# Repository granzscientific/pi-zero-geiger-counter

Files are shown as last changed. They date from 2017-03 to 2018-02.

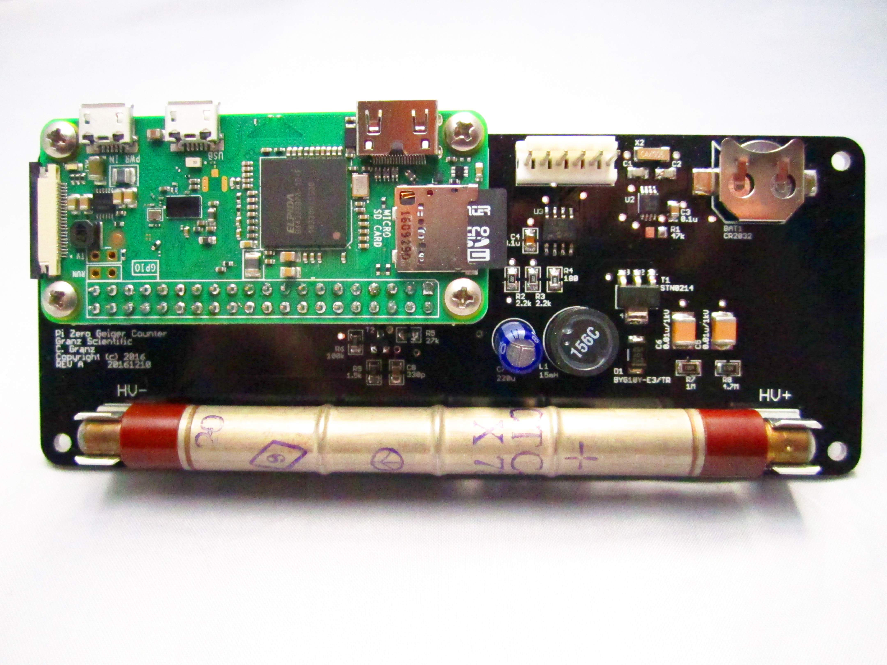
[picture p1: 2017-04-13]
images/REV A/IMG_2126.JPG

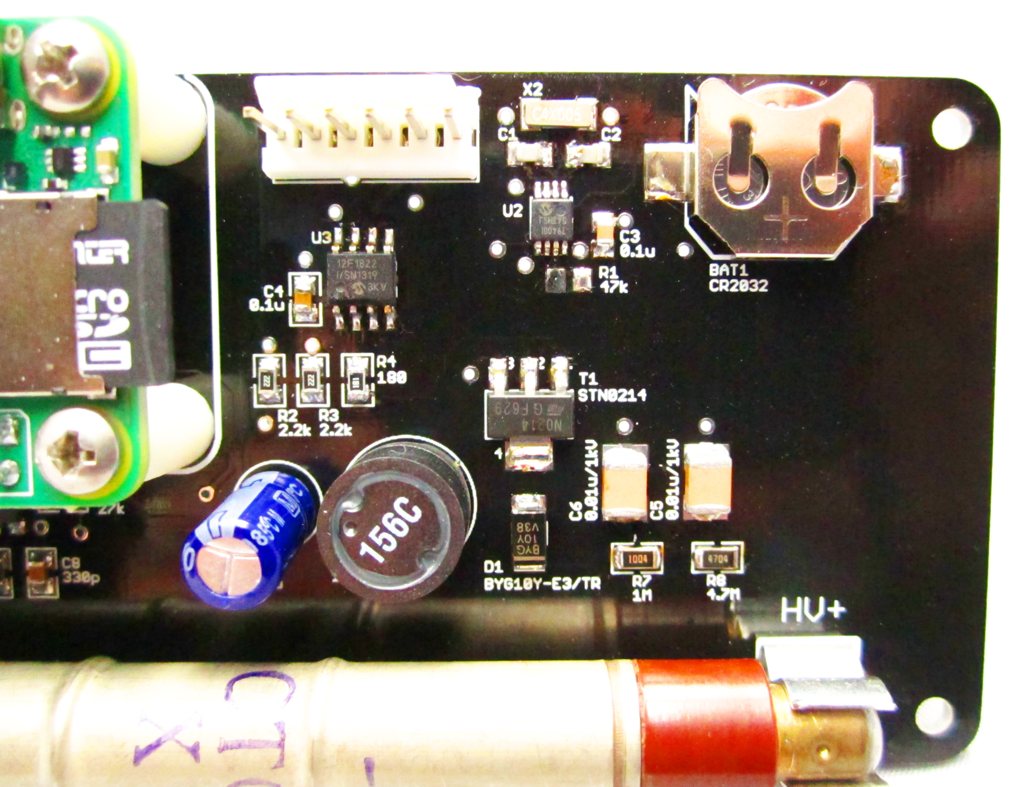
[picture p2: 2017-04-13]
images/REV A/IMG_2129.JPG

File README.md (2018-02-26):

# pyGI/webGI - A Web interface for the Granz Scientific Raspberry Pi Zero Geiger Counter

Python/HTML5/CSS/JS/Websocket software suite for collecting, distributing,
monitoring, mapping and analyzing ionizing radiation counts detected by the PiGI-Module.

This software stack is based on the Raspberry Pi Geiger Counter project described here:

http://projects-raspberry.com/pigi-raspberry-pi-geiger-muller-interface/

and here:

https://apollo.open-resource.org/lab:pigi

## Sneak-Preview: Development screenshots in action

### Main instrument panel

### History instrument panel

### Ion trace visualizer


## Installation

### Dependencies

We've tried to keep external dependencies to a minimum to make it easily
deployable on any flavor of open-source operating system. If you deploy it
successfully on any other OS, please update this:

#### Currently tested versions

    * greenlet-0.4.2
    * bottle-0.12.4
    * gevent-1.0
    * gevent-websocket-0.9.3

#### Ubuntu/Raspbian

    $ sudo apt-get install python-pip python-dev libevent-dev
    $ sudo pip install ez-setup
    $ sudo pip install leveldb greenlet bottle gevent gevent-websocket

#### Raspberry Pi deployment

If you want to deploy the code on a Pi for production in order to count
values from a real GM tube connected to the Pi, you have to make sure to
satisfy the RPi.GPIO dependency:

    * pip install RPi.GPIO

This only applies to non-Raspbian installations, since Raspbian ships
RPi.GPIO with the default installation.

### Clone repo

    $ git clone https://github.com/granzscientific/pi-zero-geiger-counter.git

## Configuration

PyGI checks 3 configuration files, if existent in conf/, updating the
values defined in the file before or using new ones, in the following order:

    * default.cfg (automatically comes shipped per default with examples)
    * local.cfg (create this file to override local server settings - gitignored)
    * dynamic.cfg (this file will be created automatically,
      if the webGI client wants to change server settings - also gitignored)

When you are deploying on the Pi to count real values and/or want to
change the Web Server/Socket port to 80 rather than 8080 __you have to
run the software as root__. Otherwise the interrupt handling on the Pi
won't work and port 80 will not be accessible due to security (<1024).

## Usage

### Server Startup

    $ cd PiGI/
    $ ./pyGIserver.py

### Client Access

Open Browser and goto http://localhost:8080

### License

This program is free software: you can redistribute it and/or modify
it under the terms of the GNU General Public License as published by
the Free Software Foundation, either version 3 of the License, or
(at your option) any later version.

This program is distributed in the hope that it will be useful,
but WITHOUT ANY WARRANTY; without even the implied warranty of
MERCHANTABILITY or FITNESS FOR A PARTICULAR PURPOSE.  See the
GNU General Public License for more details.

You should have received a copy of the GNU General Public License
along with this program.  If not, see <http://www.gnu.org/licenses/>.

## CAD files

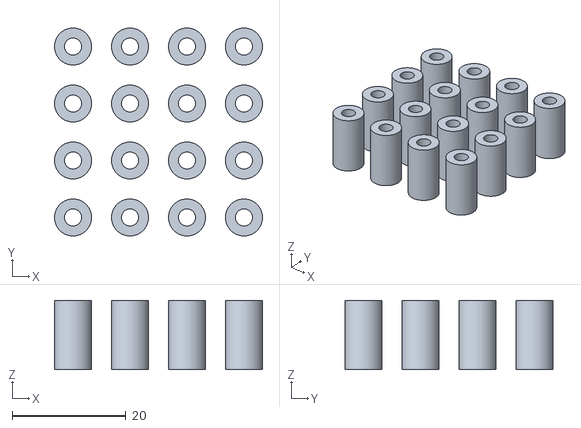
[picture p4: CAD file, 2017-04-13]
cad/PiStandoff.stl
36.5 x 36.5 x 12.2

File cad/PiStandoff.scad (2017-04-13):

translate([15,5,0]) Standoff();
translate([5,5,0]) Standoff();
translate([15,-5,0]) Standoff();
translate([5,-5,0]) Standoff();

translate([-5,5,0]) Standoff();
translate([-15,5,0]) Standoff();
translate([-5,-5,0]) Standoff();
translate([-15,-5,0]) Standoff();

translate([15,25,0]) Standoff();
translate([5,25,0]) Standoff();
translate([15,15,0]) Standoff();
translate([5,15,0]) Standoff();

translate([-5,25,0]) Standoff();
translate([-15,25,0]) Standoff();
translate([-5,15,0]) Standoff();
translate([-15,15,0]) Standoff();

module Standoff()
{
	difference()
	{
		cylinder(h=12.15, r=6.5/2, $fn=70);
		cylinder(h=100, r=3/2, $fn=70);
	}
}

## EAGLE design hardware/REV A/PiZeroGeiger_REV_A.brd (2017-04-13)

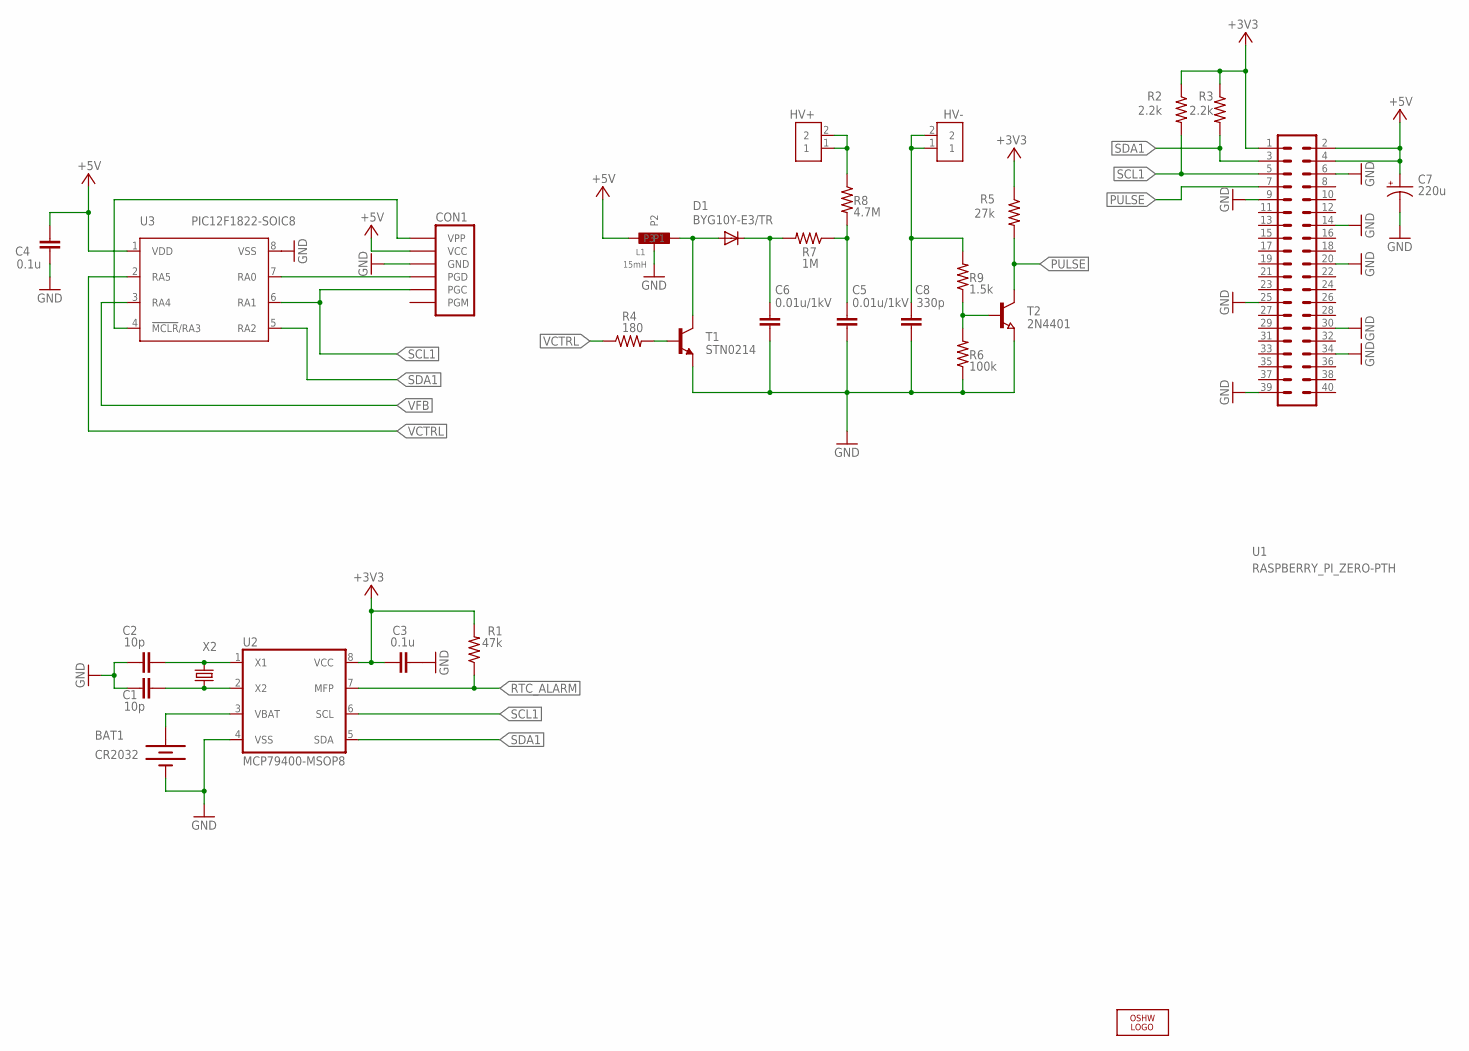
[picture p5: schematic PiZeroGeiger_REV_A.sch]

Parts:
BAT1: CR2032; BATTERY_HOLDER_12MM_BK-885
C1, C2: 10p; RCL_0805
C3, C4: 0.1u; RCL_0805
C5, C6: 0.01u/1kV; RCL_1812
C7: 220u; CAPACITOR_POLARIZED_PTH_2.5MM-7MM
C8: 330p; RCL_0805
CON1: CON_PIC_ICSP; CON_INLINE_TE_640456-6
D1: BYG10Y-E3/TR; DO-214AC
HV+: FUSE_HOLDER-PTH; FUSE_HOLDER_PTH
HV-: FUSE_HOLDER-PTH; FUSE_HOLDER_PTH
L1: 15mH; 1200LRS
LOGO1: OSHW_LOGO_FILLX0150-NT; OSHW_FILLX150_NOTEXT
R1: 47k; RCL_0805
R2, R3: 2.2k; RCL_0805
R4: 180; RCL_0805
R5: 27k; RCL_0805
R6: 100k; RCL_0805
R7: 1M; RCL_0805
R8: 4.7M; RCL_0805
R9: 1.5k; RCL_0805
T1: STN0214; SOT223
T2: 2N4401; SOT23
U1: RASPBERRY_PI_ZERO-PTH; RASPBERRY_PI_ZERO
U2: MCP79400-MSOP8; MSOP8
U3: PIC12F1822-SOIC8; SOIC8
X2: 32.768 kHz 12.5 pF X1123-ND; CRYSTAL_ABRACON_ABS10

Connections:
+3V3: C3.2, R1.2, R2.1, R3.1, R5.1, U1.1, U2.8 (VCC)
+5V: C4.1, C7.+, CON1.5 (VCC), L1.P1, U1.2, U1.4, U3.1 (VDD)
DIS: R4.2, T1.1 (B)
GND: BAT1.-, C1.2, C2.2, C3.1, C4.2, C5.2, C6.2, C7.-, C8.2, CON1.4 (GND), L1.P4 (P2), R6.1, T1.3 (E), T2.2 (E), U1.6, U1.9, U1.14, U1.20, U1.25, U1.30, U1.34, U1.39, U2.4 (VSS), U3.8 (VSS)
unnamed: CON1.6 (VPP), U3.4 (!MCLR!/RA3)
unnamed: C6.1, D1.C, R7.2
unnamed: CON1.3 (PGD), U3.7 (RA0)
unnamed: D1.A, L1.P3, T1.4 (C)
unnamed: C5.1, R7.1, R8.2
unnamed: R6.2, R9.1, T2.1 (B)
unnamed: C8.1, HV-.1, HV-.2, R9.2
unnamed: HV+.1, HV+.2, R8.1
unnamed: C1.1, U2.2 (X2), X2.1
unnamed: C2.1, U2.1 (X1), X2.2
unnamed: BAT1.+A (+), U2.3 (VBAT)
PULSE: R5.2, T2.3 (C), U1.7
RTC_ALARM: R1.1, U2.7 (MFP)
SCL1: CON1.2 (PGC), R2.2, U1.5, U2.6 (SCL), U3.6 (RA1)
SDA1: R3.2, U1.3, U2.5 (SDA), U3.5 (RA2)
VCTRL: R4.1, U3.2 (RA5)
VFB: U3.3 (RA4)

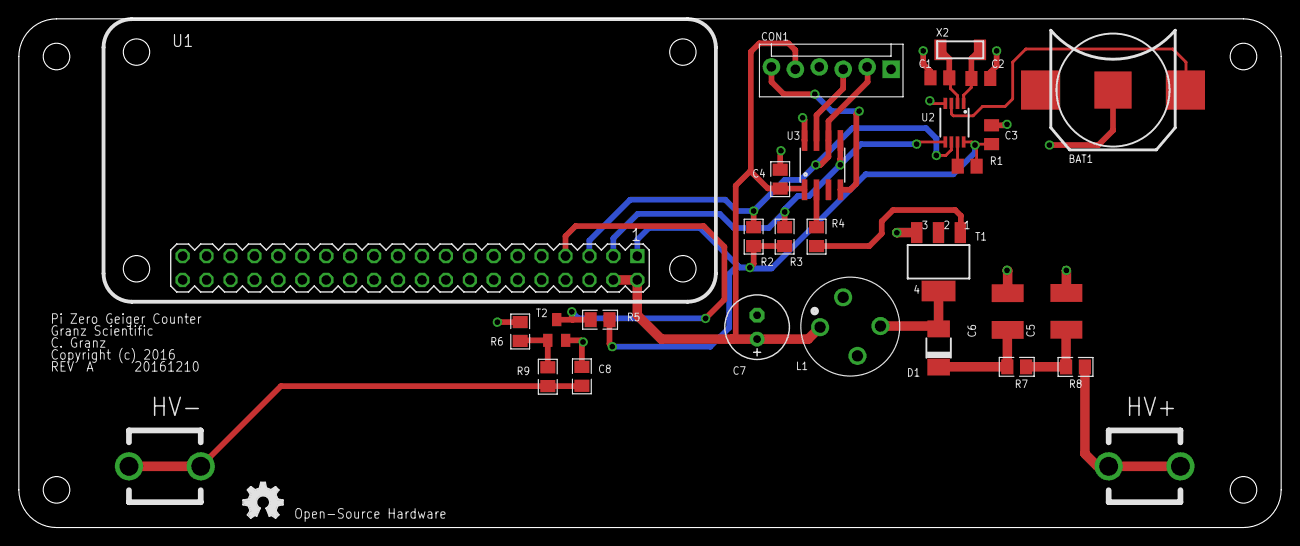
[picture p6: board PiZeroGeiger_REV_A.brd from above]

Board: 2 copper layers, 134.0 x 54.0 mm, 31 parts (0 on the bottom side), 20 nets.

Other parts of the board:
U$1: INFO_BOARD1

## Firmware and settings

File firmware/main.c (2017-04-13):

///////////////////////////////////////////////////////////////////////////////
// Author: Christopher D. Granz
// 2013-02-25
//
// Copyright (c) 2013 - Christopher D. Granz
// All rights reserved.
//
// This code is written for the Microchip XC8 Compiler.
// MCU: 12F1822
///////////////////////////////////////////////////////////////////////////////

#include "PlatformPIC.h"

//#define USING_BOOTLOADER

// set microcontroller ID, used for firmware version number
#define FIRMWARE_VERSION                0x01

__IDLOC7(0x00,0x00,FIRMWARE_VERSION,0x00);

// processor configuration bits
__CONFIG(BOREN_OFF & PWRTE_OFF & WDTE_ON & MCLRE_OFF & FOSC_INTOSC & CLKOUTEN_OFF & IESO_OFF & FCMEN_OFF); // Configuration Word 1
__CONFIG(WRT_ALL & PLLEN_OFF & STVREN_ON & BORV_LO & LVP_OFF); // Configuration Word 2

///////////////////////////////////////////////////////////////////////////////
// Definitions
///////////////////////////////////////////////////////////////////////////////
typedef signed char				Int8;
typedef signed int				Int16;
typedef unsigned char			UInt8;
typedef unsigned int			UInt16;

#define _XTAL_FREQ				8000000 // for __delay_ms() and __delay_us macros

// I2C Slave address
#define I2C_DEFAULT_SLAVE_ADDRESS       0x32

// I/O config
#define I2C_SCL_TRIS_BIT		TRISA1
#define I2C_SDA_TRIS_BIT		TRISA2

#define FET_GPIO_BIT			LATA5
#define FET_TRIS_BIT			TRISA5

#define EEPROM_ADDRESS_I2C_ADDRESS      0x10

///////////////////////////////////////////////////////////////////////////////
// Globals
///////////////////////////////////////////////////////////////////////////////
volatile UInt8 SSP1STATSave; // I2C management variables
volatile UInt8 I2CInBuffer[5];
volatile UInt8 I2COutBuffer[5];
volatile UInt8 I2CInBufIndex;
volatile UInt8 I2COutBufIndex;

char Temp[6]; // Temperary storage for several functions

UInt8 Temp1;
UInt8 Temp2;

#ifdef USING_BOOTLOADER
// WARNING don't change this, it is simply here to make the compiler
// learn that memory location alone
int UserAppMode @ 0x79;
int Reserved_A @ 0x7C; // used by bootloader ISR
#endif

///////////////////////////////////////////////////////////////////////////////
// Function Prototypes
///////////////////////////////////////////////////////////////////////////////
void interrupt ISRDispatch(void);
void I2CSlaveSetup(UInt8 address);
void ISRI2C(void);
UInt8 EEPROMReadByte(UInt8 addr);
void EEPROMWriteByte(UInt8 addr, UInt8 data);
void DelayMs(UInt8 ms);

///////////////////////////////////////////////////////////////////////////////
// Main program entry point.
///////////////////////////////////////////////////////////////////////////////
void main()
{
    UInt8 newI2CAddress;
    UInt8 lockoutI2CAddressChange;
    UInt8 i, j, k;

    // Set the oscillator frequency to 16MHz internal clock
    OSCCON = 0b01111000;

    // Set watchdog timeout for 4 seconds
    WDTCON = 0b00011001;

    ANSELA = 0x00; // all pins as digital

    INTCON = 0b11000000;

    // Now enable the correct outputs (others stay as inputs)
    FET_GPIO_BIT = 0;
    FET_TRIS_BIT = 1;

    __delay_ms(200); // power up delay before reading EEPROM

    // Setup the I2C slave module
    if ((newI2CAddress = EEPROMReadByte(EEPROM_ADDRESS_I2C_ADDRESS)) == 0x00
            || newI2CAddress == 0xFF)
    {
        newI2CAddress = I2C_DEFAULT_SLAVE_ADDRESS;
    }

    //I2CSlaveSetup(newI2CAddress);
    I2CSlaveSetup(I2C_DEFAULT_SLAVE_ADDRESS);

    newI2CAddress = 0x00;
    lockoutI2CAddressChange = 0;

    // setup the PWM module
    CCP1SEL = 1; // PWM on RA5
//    PR2 = 0x65;
    PR2 = 0xFF;
    CCPR1L  = 0x00;
    CCP1CON = 0b00001100; // single output mode = 00, LSBs of duty-cycle = 11, active-high for all signals = 1100

    PIR1bits.TMR2IF = 0;
    T2CON = 0b01111100;

    // wait for timer overflow
    while (!PIR1bits.TMR2IF) { }

    FET_TRIS_BIT = 0; // now enable output driver to begin PWM output

    // The firmware version is always the third byte if it is read...
    I2COutBuffer[2] = FIRMWARE_VERSION;

    /*
    CCPR1L = 238;
    CCP1CON &= 0b11001111;
    FET_TRIS_BIT = 0;
    while(1){}
*/

    while(1)
    {
        asm("CLRWDT"); // Clear watchdog timer

        __delay_ms(1);

        // Disable I2C interrupts--critical section for I2C buffer variables
        SSP1IE = 0;

        /*
        // Do we need to update the I2C address?
        if (!lockoutI2CAddressChange && newI2CAddress != 0x00
                && newI2CAddress != 0xFF)
        {
            SSPEN = 0; // disable module
            __delay_ms(20);
            I2CSlaveSetup(newI2CAddress);
            EEPROMWriteByte(0x10, newI2CAddress);
            newI2CAddress = 0x00;
            SSP1IE = 0;
        }

        if (!lockoutI2CAddressChange && I2CInBuffer[0] == 0x91)
        {
            if (I2CInBuffer[1] == 0x24 && I2CInBufIndex > 2)
            {
                I2CInBuffer[0] = 0;
                I2CInBuffer[1] = 0;

                newI2CAddress = I2CInBuffer[2];

                I2CInBuffer[2] = 0;
            }
        }
        else */
        {
            k = I2CInBuffer[0];

            if (k < 1)
                FET_TRIS_BIT = 1; // disable output
            else
            {
                lockoutI2CAddressChange = 1;
                GCEN = 0;
                FET_TRIS_BIT = 0; // enable output
            }
        }

        SSP1IE = 1;

        CCPR1L = k;
        CCP1CON &= 0b11001111;
    }
}

///////////////////////////////////////////////////////////////////////////////
// Main interrupt service routine.
///////////////////////////////////////////////////////////////////////////////
void interrupt ISRDispatch()
{
    // NOTE: this processor has automatic context saving

    if (SSP1IF)
    {
        SSP1IF = 0;
        ISRI2C();
    }

#ifdef USING_BOOTLOADER
    // do a normal RETURN here, not a RETURN-FROM-INTERRUPT because of bootloader
    // (which has the "real" ISR)
#asm
    RETURN ;
#endasm
#endif
}

///////////////////////////////////////////////////////////////////////////////
void ISRI2C()
{
    static UInt8 generalCall = 0;
    // We are interested in these bits of the status register:
    //  bit 7 - SMP - Don't care
    //  bit 6 - CKE - Don't care
    //  bit 5 - D/!A: Data/!Address bit
    //  1 = Last byte received/transmitted was a data byte
    //  0 = Last byte received/transmitted was an address byte
    //  bit 4 - P - Don't care
    //  bit 3 - S - Start bit
    //				1 = Indicates that a Start bit has been detected last
    //				0 = Start bit was not detected last
    //	bit 2 - R/W: Read/Write bit information
    //				This bit holds the R/W bit information following the last address match
    //				This bit is only valid from the address match to the next Start bit, Stop bit, or not ACK bit
    //				1 = Read
    //				0 = Write
    //	bit 1 - UA - Don't care
    //	bit 0 - BF: Buffer Full Status bit
    //				Receive (SPI and I2C modes):
    //					1 = Receive complete, SSP1BUF is full
    //					0 = Receive not complete, SSP1BUF is empty
    //				Transmit (I2C mode only):
    //					1 = Data transmit in progress (does not include the ACK and Stop bits), SSP1BUF is full
    //					0 = Data transmit complete (does not include the ACK and Stop bits), SSP1BUF is empty

    // save a snapshot so it doesn't change while we are reading it
    SSP1STATSave = (SSP1STAT & 0b00101101);

    if (SSP1STATSave == 0b00001001) // State 1: Master Write, Last Byte was an Address
    {
        Temp1 = SSP1BUF; // clear buffer

        if (Temp1 == 0x00)
            generalCall = 1;
        else
            generalCall = 0;

        I2CInBufIndex = 0;
        CKP = 1; // release SCL
        return;
    }

    if (SSP1STATSave == 0b00101001) // State 2: Master Write, Last Byte was Data
    {
GeneralCallWrite:
        I2CInBuffer[I2CInBufIndex] = SSP1BUF;

        if (++I2CInBufIndex == sizeof(I2CInBuffer))
            I2CInBufIndex = 0;

        CKP = 1; // release SCL
        return;
    }

    SSP1STATSave &= 0b00101100;

    if (SSP1STATSave == 0b00001100) // State 3: Master Read, Last Byte was an Address
    {
        Temp1 = SSP1BUF; // clear buffer

        if (Temp1 == 0x00)
        {
            generalCall = 1;
            I2CInBufIndex = 0;
        }
        else
        {
            generalCall = 0;
            SSP1BUF = I2COutBuffer[0];
            I2COutBufIndex = 1;
        }

        CKP = 1; // release SCL
        return;
    }

    if (SSP1STATSave == 0b00101100 && !CKP) // State 4: Master Read, Last Byte was Data
    {
        if (generalCall == 1)
            goto GeneralCallWrite;

        if (!ACKSTAT)
        {
            SSP1BUF = I2COutBuffer[I2COutBufIndex];

            if (++I2COutBufIndex == sizeof(I2COutBuffer))
                I2COutBufIndex = 0;
        }

        CKP = 1; // release SCL
        return;
    }

    SSP1STATSave &= 0b00101000;

    if (SSP1STATSave == 0b00101000) // Master reset with NACK
    {
        if (generalCall == 1)
            goto GeneralCallWrite;

        CKP = 1; // release SCL
        return;
    }
    else
    {
        if (generalCall == 1)
            goto GeneralCallWrite;

        // Error condition
        CKP = 1; // release SCL
        return;
    }
}

///////////////////////////////////////////////////////////////////////////////
// Configure the I2C module for slave operation.
///////////////////////////////////////////////////////////////////////////////
void I2CSlaveSetup(UInt8 address)
{
    UInt8 i;

    // set I/Os as inputs for I2C operation
    I2C_SCL_TRIS_BIT = 1;
    I2C_SDA_TRIS_BIT = 1;

    for (i = 0; i < sizeof(I2CInBuffer); i++)
        I2CInBuffer[i] = 0;

    for (i = 0; i < sizeof(I2COutBuffer); i++)
        I2COutBuffer[i] = 0;

    SSP1ADD  = address;

    SSP1CON1 = 0b00110110;
    SSP1CON2 = 0b10000001;
    SSP1CON3 = 0b00010000;

    SSP1STAT = 0b10000000;

    SSPEN = 1; // enable the module

    SSP1IF = 0;
    SSP1IE = 1;
}

///////////////////////////////////////////////////////////////////////////////
UInt8 EEPROMReadByte(UInt8 addr)
{
    Temp1 = addr;

#asm
    BANKSEL _Temp1 ;
    MOVF _Temp1, W ;
    BANKSEL EEADRL ;
    MOVWF EEADRL ; Data Memory
    ; Address to read
    BCF _EECON1, 6  ; Deselect Config space
    BCF _EECON1, 7 ; Point to DATA memory
    BSF _EECON1, 0 ; EE Read
    MOVF EEDATL, W ; W = EEDATL
    BANKSEL _Temp2 ;
    MOVWF _Temp2 ; Temp2 = W
#endasm

    return Temp2;
}

///////////////////////////////////////////////////////////////////////////////
void EEPROMWriteByte(UInt8 addr, UInt8 data)
{
    Temp1 = addr;
    Temp2 = data;

#asm
    BANKSEL _Temp1 ;
    MOVF _Temp1, W ;
    BANKSEL EEADRL ;
    MOVWF EEADRL ; Data Memory Address to write
    BANKSEL _Temp2 ;
    MOVF _Temp2, W ;
    BANKSEL EEADRL ;
    MOVWF EEDATL ; Data Memory Value to write
    BCF _EECON1, 6 ; Deselect Configuration space
    BCF _EECON1, 7 ; Point to DATA memory
    BSF _EECON1, 2 ; Enable writes
    BCF _INTCON, 7 ; Disable INTs.
    MOVLW 55h ;
    MOVWF _EECON2 ; Write 55h
    MOVLW 0AAh ;
    MOVWF _EECON2 ; Write AAh
    BSF _EECON1, 1 ; Set WR bit to begin write
    BSF _INTCON, 7 ; Enable Interrupts
    BCF _EECON1, 2 ; Disable writes
    BTFSC _EECON1, 1 ; Wait for write to complete
    GOTO $-2 ; Done
#endasm
}

///////////////////////////////////////////////////////////////////////////////
// Delay for the specified number of milliseconds.
///////////////////////////////////////////////////////////////////////////////
void DelayMs(UInt8 ms)
{
    // Just use the built-in delay function for now
    // We need this wrapper when using a variable to specify the time
    // because the __delay_ms() function is inline, and only works
    // with a constant value.
    while (ms-- > 0)
        __delay_ms(1);
}

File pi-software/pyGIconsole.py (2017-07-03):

#!/usr/bin/env python
import logging
import time
from pyGI.configurator import cfg

#setup logging
log = logging.getLogger()
log.setLevel(cfg.get('logging','level'))
formatter = logging.Formatter('%(asctime)s %(levelname)s %(name)s: %(message)s')
if cfg.getboolean('logging','write_file'):
    filehandler = logging.FileHandler(cfg.get('logging','filename'))
    filehandler.setFormatter(formatter)
    log.addHandler(filehandler)
streamhandler = logging.StreamHandler()
streamhandler.setFormatter(formatter)
log.addHandler(streamhandler)

if __name__ == "__main__":
    log.info("Starting pyGIconsole")
    from pyGI import geigercounter,geigerlog
    try:
        # get last totalcount from db
        (last_total,last_total_dtc) = geigerlog.get_last_totalcount()
        log.info("Last total: %d, total_dtc: %d"%(last_total, last_total_dtc))

        # start geigercounter
        geiger = geigercounter.Geigercounter(total=last_total, total_dtc=last_total_dtc)

        # start geigercounter logging
        geigerlog = geigerlog.GeigerLog(geiger)

        # loop, reporting rates

        last_ticks = geiger.totalcount
        log.info("Starting ticks update loop")
        while True:
            ticks = geiger.totalcount-last_ticks
            last_ticks = geiger.totalcount
            log.info("CPS: " + str(geiger.cps))
            log.info("CPM: " + str(geiger.cpm))
            time.sleep(0.5)

    except KeyboardInterrupt:
        log.info("Stopping pyGIconsole")
        geiger.reset() # stop hardware HV generator

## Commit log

2017-03-22 Initial commit.
    [default.cfg]
2017-04-13 Added hardware design files and PIC firmware.
    [PiStandoff.scad, PiStandoff.stl, PiZeroGeiger_REV_A.brd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]
2017-04-24 Fixed disconnect issue with web interface (hopefully). Fixed README to correct Pi Zero version (not old apollo version). Other minor changes.
    [default.cfg]
2017-04-24 Fixed default input pin in pyGI server.
    [default.cfg]
2017-04-24 Slight changed to pulse width for HV tube supply. Added geiger_off.py to quickly turn off the HV supply.
2017-07-03 Fix to turn off HV supply when program exits. Renamed geiger_off.py and geiger_test.py to geigeroff.py and geigertest.py for consistency. Added pyGIconsole.py which runs the same geigercounter module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
    [geigercounter.py, geigertest.py, pyGIconsole.py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]

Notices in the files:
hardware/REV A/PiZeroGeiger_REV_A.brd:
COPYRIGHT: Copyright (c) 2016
